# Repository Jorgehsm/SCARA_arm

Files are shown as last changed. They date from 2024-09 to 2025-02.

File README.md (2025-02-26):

# SCARA robotic arm
Braço robótico com 4DOF baseado em esp32.

Utiliza motores de passo com redução por correia para movimento e servo MG996r para controle da pinça.

Projeto pessoal em desenvolvimento

## Projeto da placa de circuito
O projeto conta com o design de uma placa de circuitos para conectar o esp32 responsável pela comunicação e controle do robô com a alimentação e drivers dos motores.

imagem

## Projeto CAD
A estrutura do robô foi pensada para fabricação por meio de impressão 3D juntamente com fuso trapezoidal e eixos de aço para movimento no eixo Z.

A transmissão para demais movimentos foi feita por meio de correias GT2 e polias impressas

A estrutura conta também com rolamentos para adicionar rigidez e auxíliar nos movimentos.



imagem

imagem

imagem

O projeto conta também com o design de uma garra atuada por meio de um motor servo e mecanismo pinhâo cremalheira para sua abertura e fechamento



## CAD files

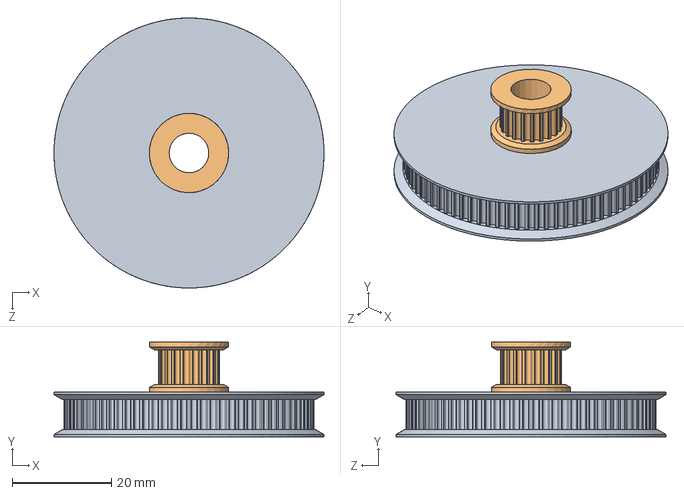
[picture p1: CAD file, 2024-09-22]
robot_arm_cad/80Tto20T/gt2-80Tto20T.SLDASM
54.4 x 19.1 x 54.4 mm
80T
20T

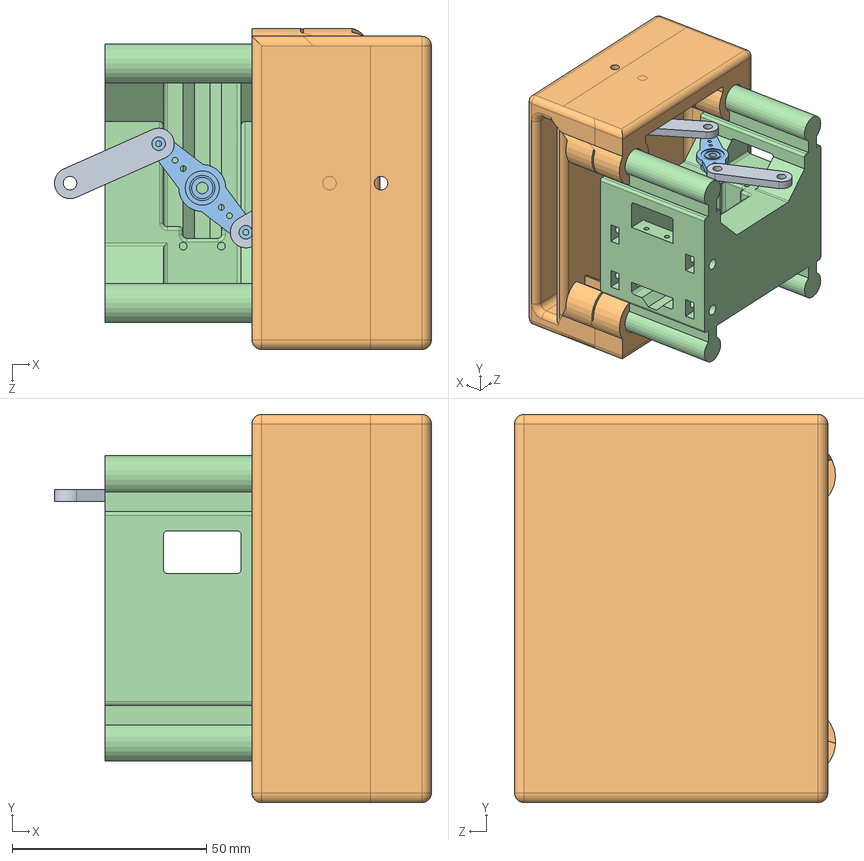
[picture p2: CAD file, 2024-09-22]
robot_arm_cad/garra/garra.SLDASM
97.1 x 100.0 x 82.7 mm
garra_corpo
attachmentStraight
presas x 2
barra x 2

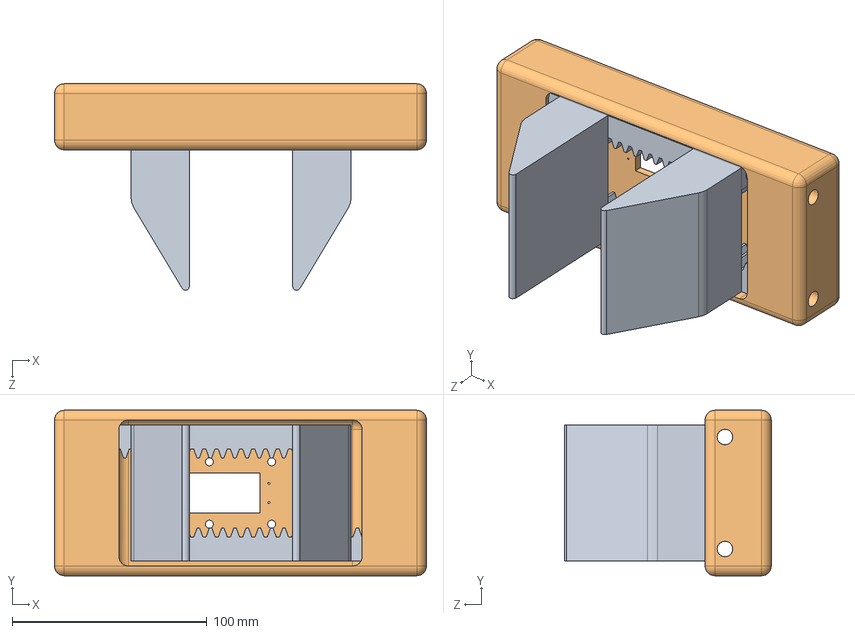
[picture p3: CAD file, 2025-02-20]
robot_arm_cad/garra_2/garra_montagem2.SLDASM
191.0 x 85.0 x 106.1 mm
corpo_garra
crermalheira_120mm x 2

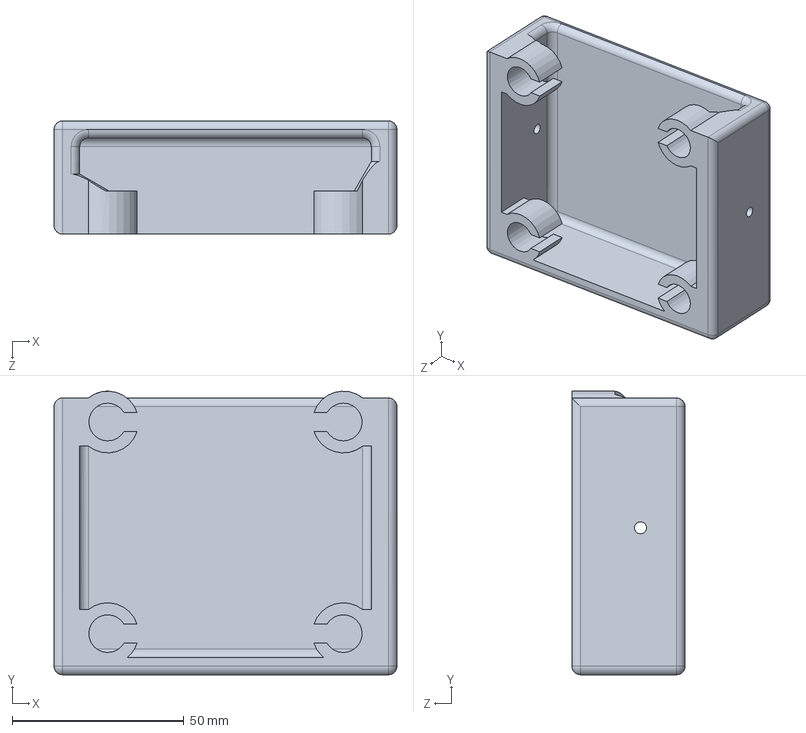
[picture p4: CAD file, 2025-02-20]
robot_arm_cad/garra/presas.SLDPRT
100.0 x 82.7 x 33.0 mm

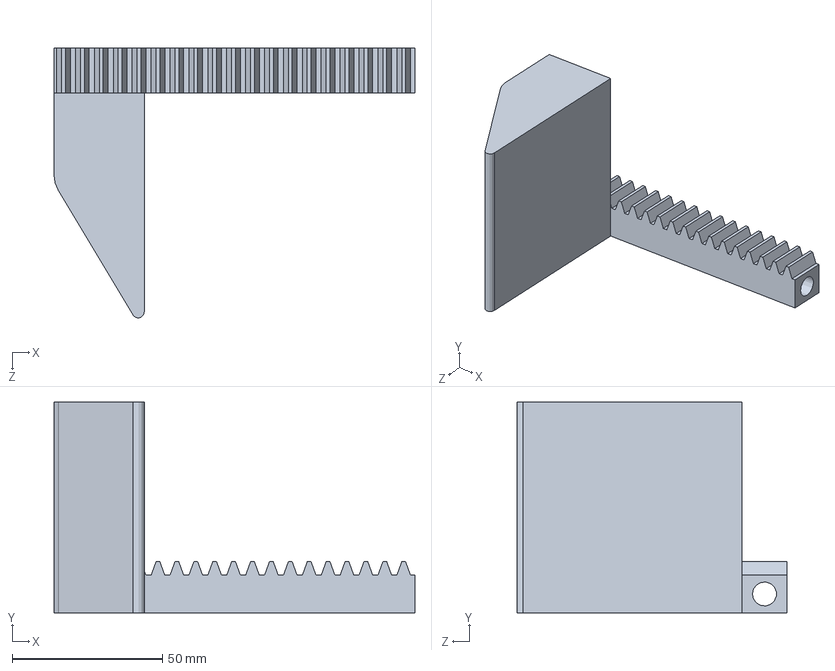
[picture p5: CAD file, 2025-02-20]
robot_arm_cad/garra_2/crermalheira_120mm.SLDPRT
120.0 x 70.0 x 89.8 mm

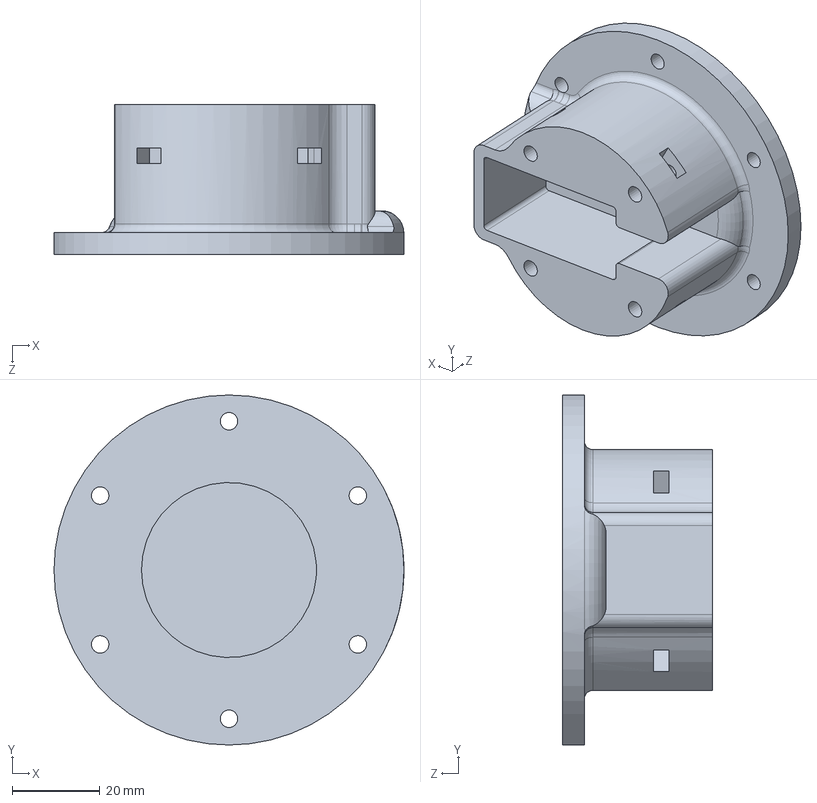
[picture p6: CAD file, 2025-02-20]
robot_arm_cad/junta_garra.SLDPRT
80.0 x 80.0 x 34.3 mm

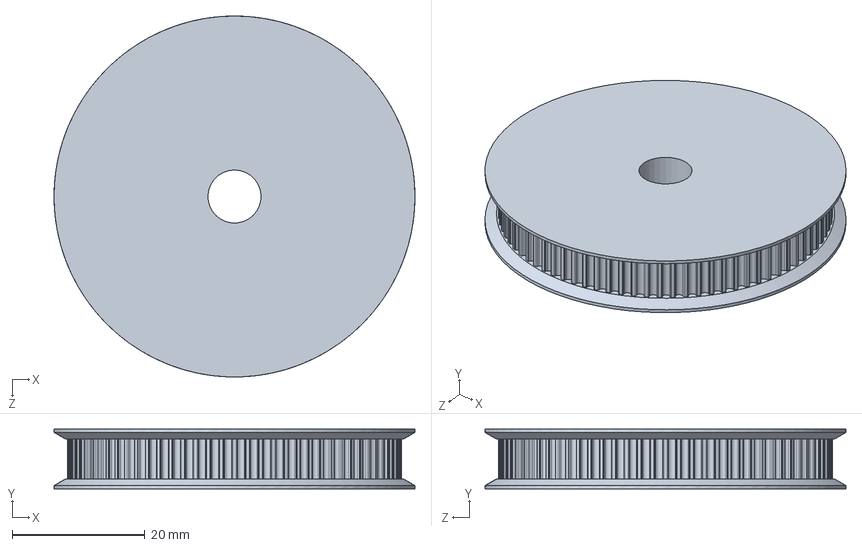
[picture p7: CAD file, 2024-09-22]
robot_arm_cad/80Tto20T/80T.SLDPRT
54.4 x 9.00 x 54.4 mm

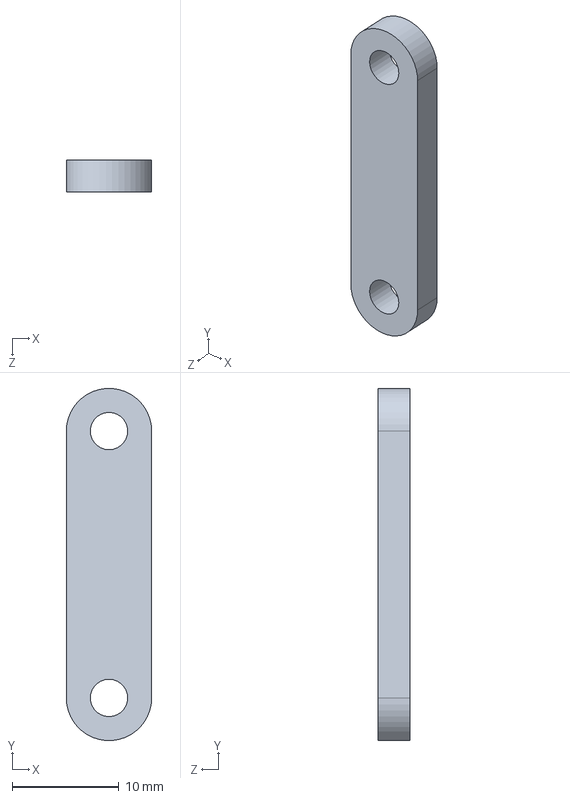
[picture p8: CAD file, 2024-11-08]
robot_arm_cad/garra/barra.SLDPRT
8.00 x 33.0 x 3.00 mm

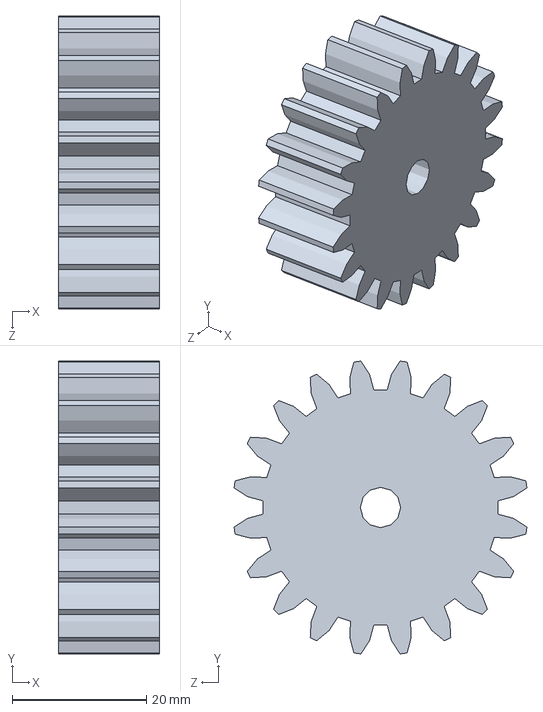
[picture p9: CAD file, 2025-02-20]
robot_arm_cad/garra_2/Metric - Spur gear 2M 20T 20PA 15FW ---S20N75H50L6N.SLDPRT
15.0 x 43.6 x 43.6 mm

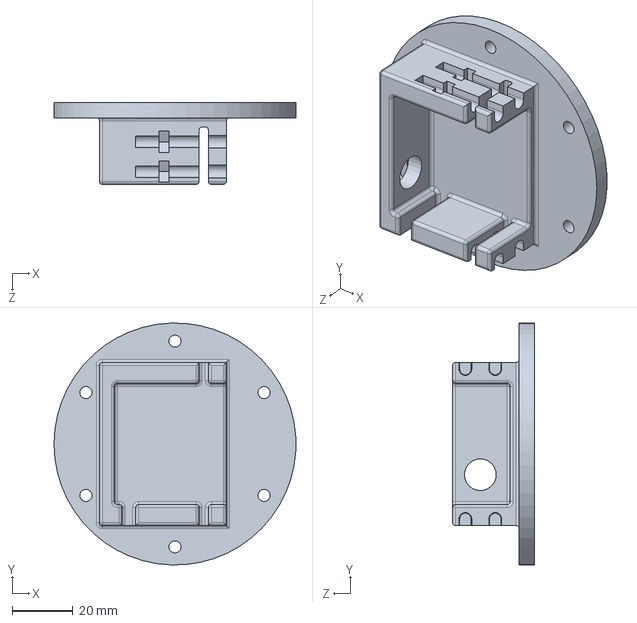
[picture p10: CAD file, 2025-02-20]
robot_arm_cad/junta_4_servo.SLDPRT
80.0 x 80.0 x 27.0 mm

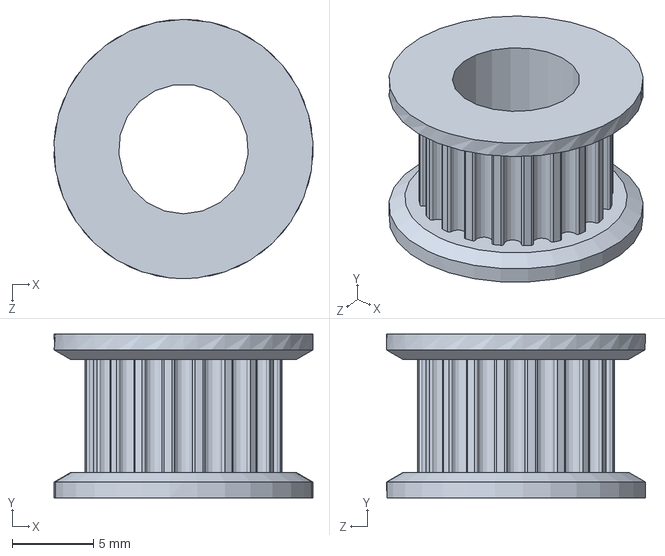
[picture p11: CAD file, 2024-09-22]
robot_arm_cad/80Tto20T/20T.SLDPRT
16.0 x 10.1 x 16.0 mm

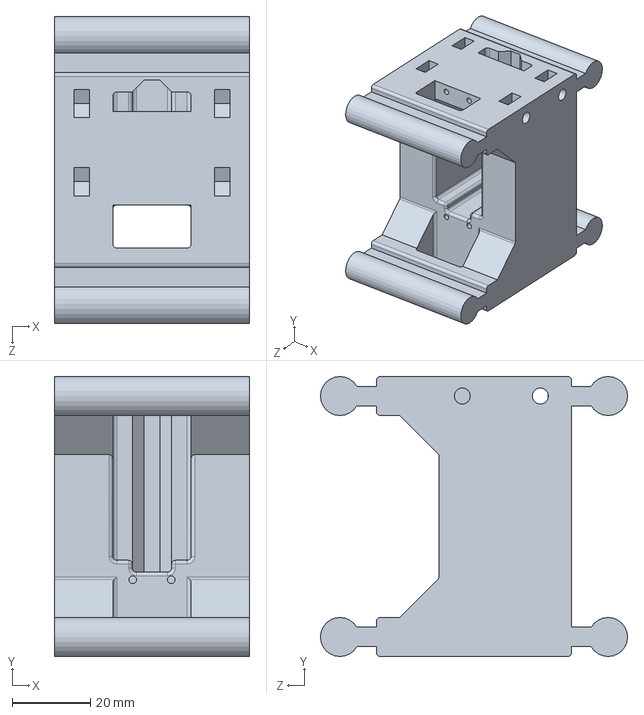
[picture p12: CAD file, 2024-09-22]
robot_arm_cad/garra/garra_corpo.SLDPRT
50.0 x 71.7 x 78.7 mm

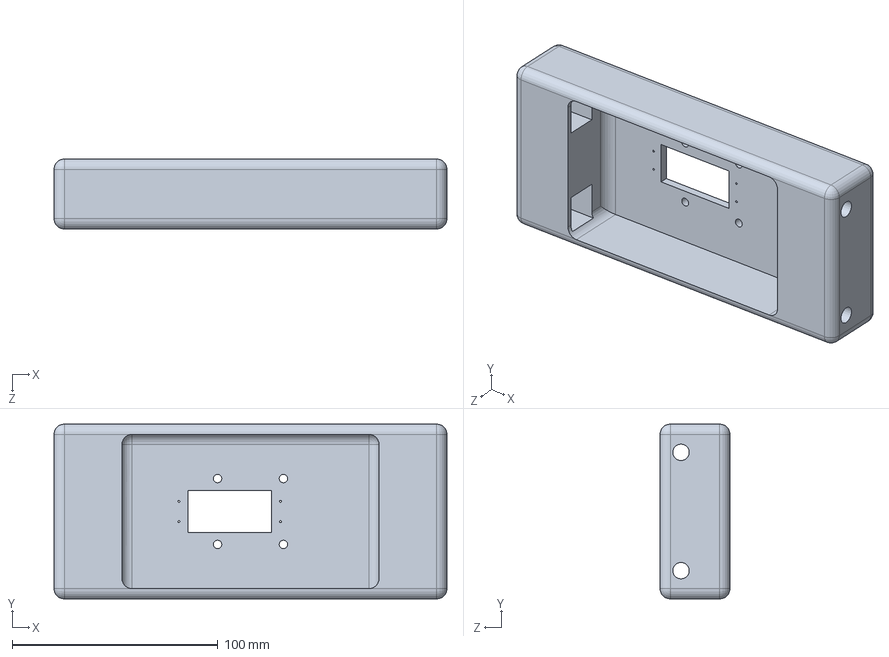
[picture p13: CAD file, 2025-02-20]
robot_arm_cad/garra_2/corpo_garra.SLDPRT
191.0 x 85.0 x 34.0 mm

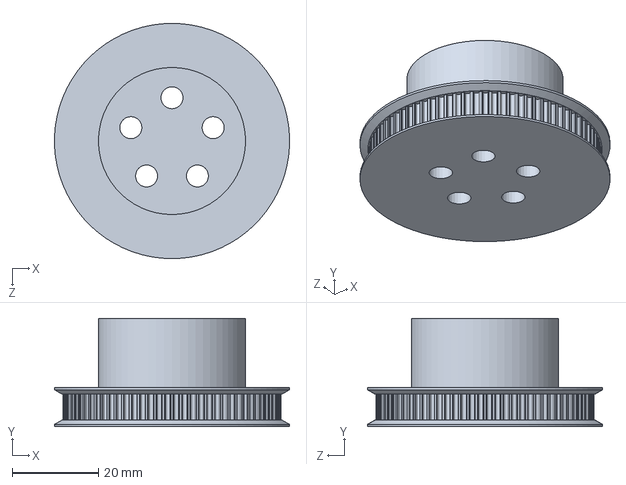
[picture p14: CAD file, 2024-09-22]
robot_arm_cad/junta_base_gt2-80T.SLDPRT
54.3 x 25.0 x 54.4 mm

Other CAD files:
robot_arm_cad/montagem_end_effector.SLDASM
robot_arm_cad/garra/attachmentStraight.SLDPRT
robot_arm_cad/ligacao_base_eixoZ.SLDPRT
robot_arm_cad/braco_1.SLDPRT
robot_arm_cad/Nema 17.SLDPRT
robot_arm_cad/POLIA GT2 20T b5.SLDPRT
robot_arm_cad/acoplamento_flexivel.SLDPRT
robot_arm_cad/base.SLDPRT
robot_arm_cad/braco_2.SLDPRT
robot_arm_cad/braco_2_inferior.SLDPRT
robot_arm_cad/castanha_TR8.SLDPRT
robot_arm_cad/cover_braco_1.SLDPRT
robot_arm_cad/garra/garra_corpo_2.SLDPRT
robot_arm_cad/garra/presa.SLDPRT
robot_arm_cad/gt2-80T.SLDPRT
robot_arm_cad/gt2-80Tto20T.SLDPRT
robot_arm_cad/gt2-parametric-pulley.SLDPRT
robot_arm_cad/guia_linear_400mm.SLDPRT
robot_arm_cad/junta gt2-80T.SLDPRT
robot_arm_cad/junta_1.SLDPRT
robot_arm_cad/junta_1_tampa.SLDPRT
robot_arm_cad/junta_2.SLDPRT
robot_arm_cad/microswitch.SLDPRT
robot_arm_cad/rolamento_linear_lm8uu.SLDPRT
robot_arm_cad/servoMotorMG996R.SLDPRT
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

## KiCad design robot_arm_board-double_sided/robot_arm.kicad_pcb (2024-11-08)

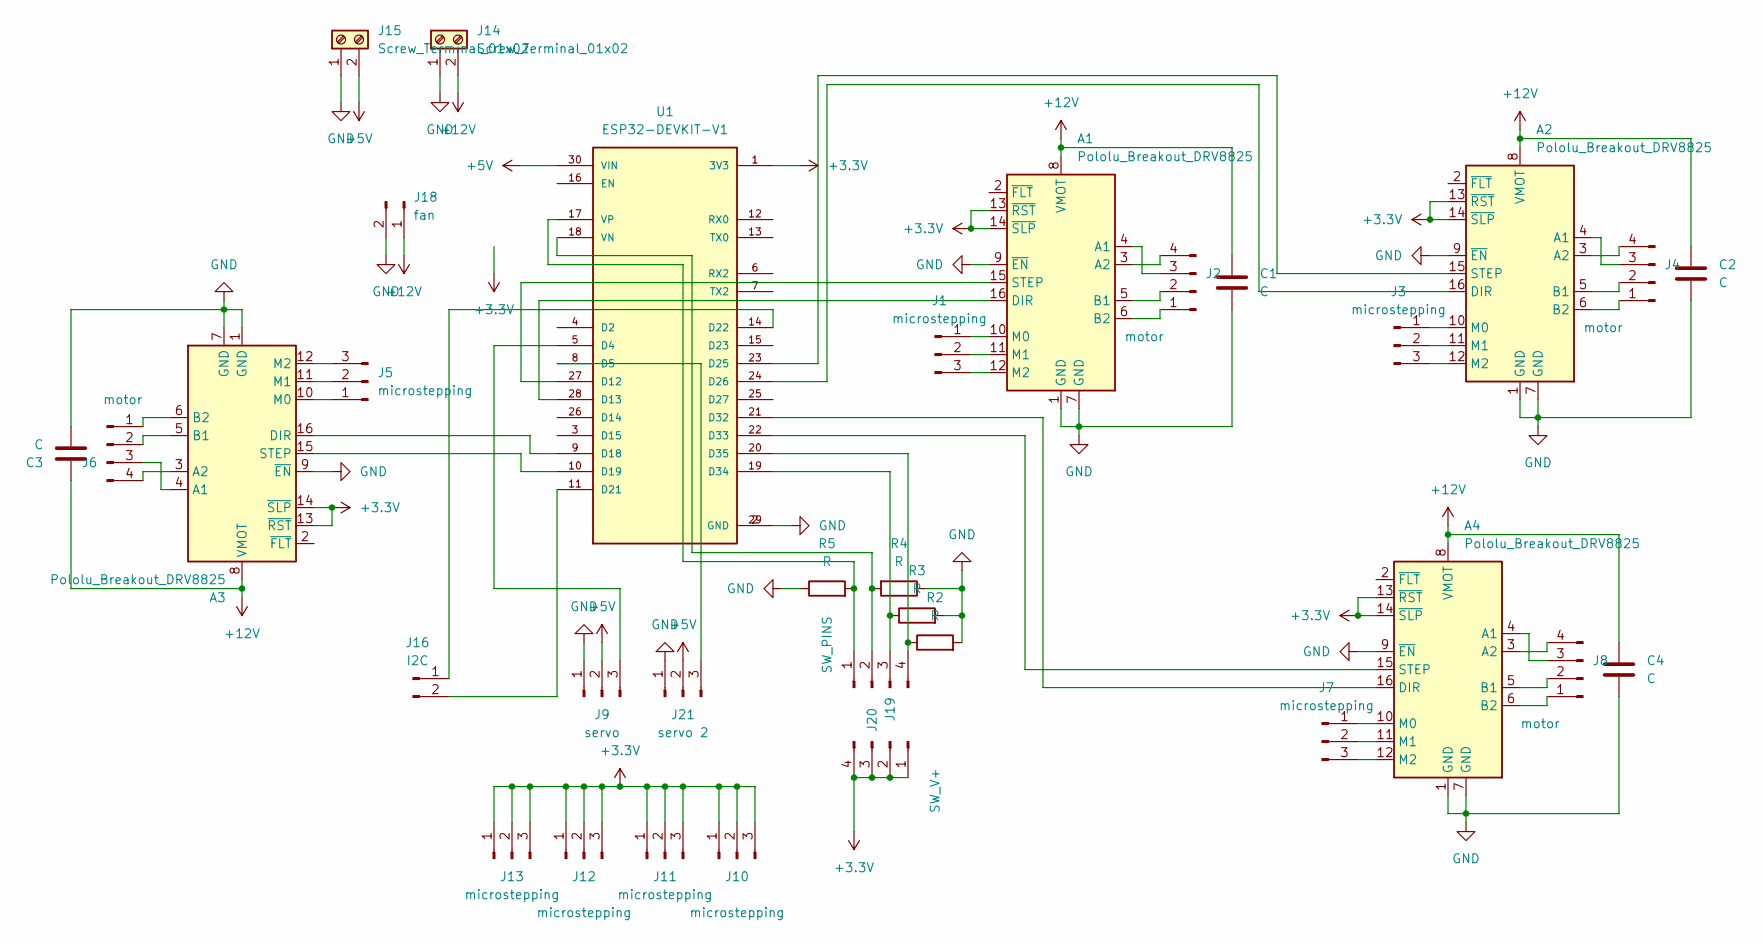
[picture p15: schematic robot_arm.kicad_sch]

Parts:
A1, A2, A3, A4: Pololu_Breakout_DRV8825; Pololu_Breakout-16_15.2x20.3mm
C1, C2, C3, C4: C; CP_Radial_D6.3mm_P2.50mm
J1, J3, J5, J7, J10, J11, J12, J13: microstepping; PinHeader_1x03_P2.54mm_Vertical
J2, J4, J6, J8: motor; PinHeader_1x04_P2.54mm_Vertical
J9: servo; PinHeader_1x03_P2.54mm_Vertical
J14, J15: Screw_Terminal_01x02; TerminalBlock_bornier-2_P5.08mm
J16: I2C; PinHeader_1x02_P2.54mm_Vertical
J18: fan; PinHeader_1x02_P2.54mm_Vertical
J19: SW_PINS; PinHeader_1x04_P2.54mm_Vertical
J20: SW_V+; PinHeader_1x04_P2.54mm_Vertical
J21: servo 2; PinHeader_1x03_P2.54mm_Vertical
R2, R3, R4, R5: R; R_Axial_DIN0204_L3.6mm_D1.6mm_P5.08mm_Horizontal
U1: ESP32-DEVKIT-V1; MODULE_ESP32_DEVKIT_V1; PARTREV N/A

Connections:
+3.3V: A1.13 (~RST), A1.14 (~SLP), A2.13 (~RST), A2.14 (~SLP), A3.13 (~RST), A3.14 (~SLP), A4.13 (~RST), A4.14 (~SLP), J10.1, J10.2, J10.3, J11.1, J11.2, J11.3, J12.1, J12.2, J12.3, J13.1, J13.2, J13.3, J20.1, J20.2, J20.3, J20.4, U1.1 (3V3)
+5V: J9.2, J15.2, J21.2, U1.30 (VIN)
+12V: A1.8 (VMOT), A2.8 (VMOT), A3.8 (VMOT), A4.8 (VMOT), C1.1, C2.1, C3.1, C4.1, J14.2, J18.1
GND: A1.1 (GND), A1.7 (GND), A1.9 (~EN), A2.1 (GND), A2.7 (GND), A2.9 (~EN), A3.1 (GND), A3.7 (GND), A3.9 (~EN), A4.1 (GND), A4.7 (GND), A4.9 (~EN), C1.2, C2.2, C3.2, C4.2, J9.1, J14.1, J15.1, J18.2, J21.1, R2.2, R3.2, R4.1, R5.1, U1.2 (GND), U1.29 (GND)
unnamed: A1.4 (A1), J2.3
unnamed: A1.3 (A2), J2.4
unnamed: A1.5 (B1), J2.2
unnamed: A1.6 (B2), J2.1
unnamed: A1.16 (DIR), U1.28 (D13)
unnamed: A1.10 (M0), J1.1
unnamed: A1.11 (M1), J1.2
unnamed: A1.12 (M2), J1.3
unnamed: A1.15 (STEP), U1.27 (D12)
unnamed: A2.4 (A1), J4.3
unnamed: A2.3 (A2), J4.4
unnamed: A2.5 (B1), J4.2
unnamed: A2.6 (B2), J4.1
unnamed: A2.16 (DIR), U1.24 (D26)
unnamed: A2.10 (M0), J3.1
unnamed: A2.11 (M1), J3.2
unnamed: A2.12 (M2), J3.3
unnamed: A2.15 (STEP), U1.23 (D25)
unnamed: A3.4 (A1), J6.3
unnamed: A3.3 (A2), J6.4
unnamed: A3.5 (B1), J6.2
unnamed: A3.6 (B2), J6.1
unnamed: A3.16 (DIR), U1.9 (D18)
unnamed: A3.10 (M0), J5.1
unnamed: A3.11 (M1), J5.2
unnamed: A3.12 (M2), J5.3
unnamed: A3.15 (STEP), U1.10 (D19)
unnamed: A4.4 (A1), J8.3
unnamed: A4.3 (A2), J8.4
unnamed: A4.5 (B1), J8.2
unnamed: A4.6 (B2), J8.1
unnamed: A4.16 (DIR), U1.21 (D32)
unnamed: A4.10 (M0), J7.1
unnamed: A4.11 (M1), J7.2
unnamed: A4.12 (M2), J7.3
unnamed: A4.15 (STEP), U1.22 (D33)
unnamed: J9.3, U1.5 (D4)
unnamed: J16.1, U1.14 (D22)
unnamed: J16.2, U1.11 (D21)
unnamed: J19.1, R5.2, U1.17 (VP)
unnamed: J19.2, R4.2, U1.18 (VN)
unnamed: J19.3, R3.1, U1.19 (D34)
unnamed: J19.4, R2.1, U1.20 (D35)
unnamed: J21.3, U1.8 (D5)

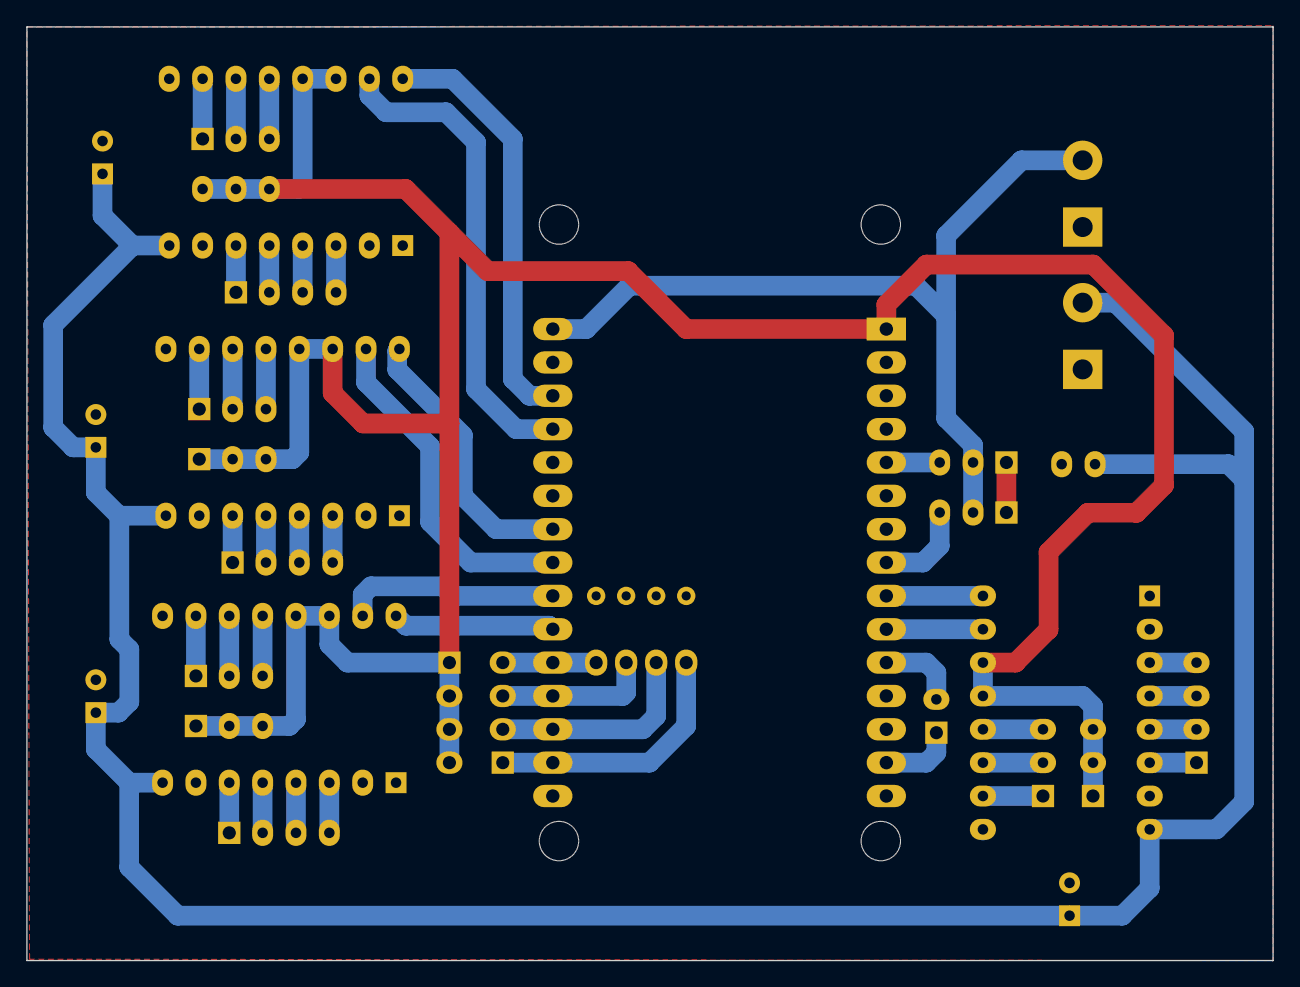
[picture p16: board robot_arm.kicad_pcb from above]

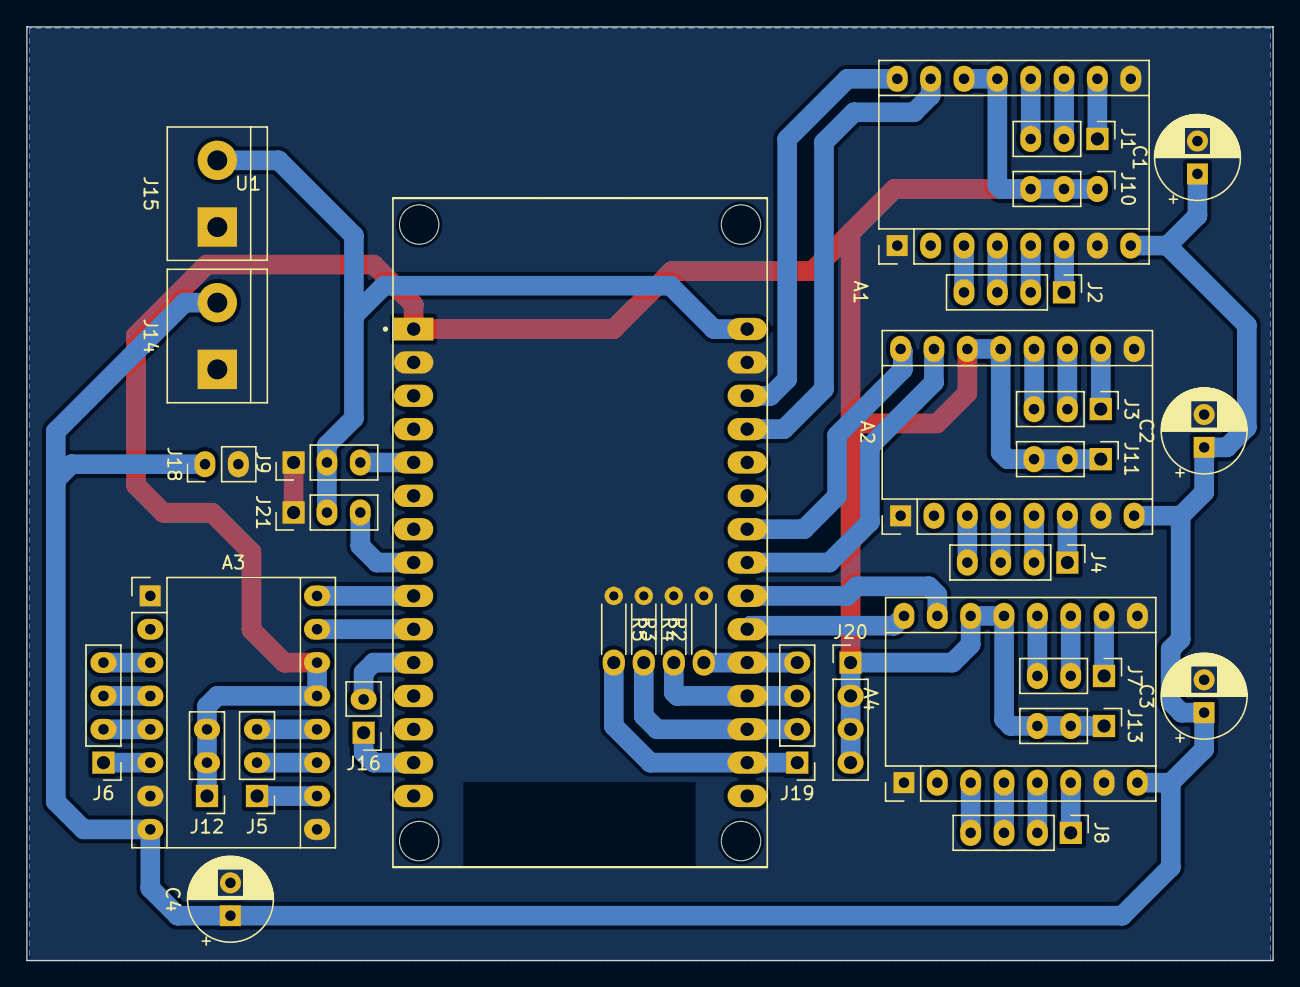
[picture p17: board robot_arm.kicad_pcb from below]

Board: 2 copper layers, 94.9 x 71.1 mm, 33 parts (33 on the bottom side), 48 nets.

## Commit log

2024-09-22 Upload arquivos de CAD e PCB
    [20T.SLDPRT, 80T.SLDPRT, Nema 17.SLDPRT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]
2024-09-22 Mudanças no CAD
    [Nema 17.SLDPRT, POLIA GT2 20T b5.SLDPRT, acoplamento_flexivel.SLDPRT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]
2024-11-08 atualizações no modelo
    [barra.SLDPRT, base.SLDPRT, braco_1.SLDPRT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]
2025-02-20 Novo modelo e montagem para garra
